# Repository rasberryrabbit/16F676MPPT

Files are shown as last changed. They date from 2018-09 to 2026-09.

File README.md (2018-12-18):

# PIC16F676MPPT
Solar MPPT circuit by 16F676. It did tested and work good.

This is simple MPPT for solar panel. PWM driven by software.

11 mili-ohm N-ch logic level FET(BUK9511) used for current sensor. 
It can replace by 11 mili-ohm or higher Rds-on resistance logic level FET.

BUK9511-55A -> BUK9508-55A
Transistor 2N2222A -> BC547 or compatible
Transistor 2N2907A -> BC557 or compatible

L1 100~330uH

LM358N can replace by other pin-compatible regular OP-AMP. HA17358 is good. It has zero offset voltage.

D8-D9 used for 3.6v Reference. Each has about 1.8v voltage drop.

Q1 gate voltage is 3.6v. It's depend on FET specification.

Q1, Q2 can skip heat spreader with low POWER Solar panel. No heat with 10W panel.

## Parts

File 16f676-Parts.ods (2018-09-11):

Part | Value | Description
R5 | 300k | Solar Voltage Detection | Max 25V
R12 | 47k | Solar Voltage Detection
D5 | 1N4007
D6 | 1N5822A | 3A
D7 | 1N5822A | 6A
C7 | 47u
U1 | 7805
C3 | 100u
C4 | 0.1u
SW1 | PUSH | OP-AMP offset calibration
U3 | PIC16F676
R16 | 10k
R6 | 1k
D4 | LED
R8 | 100k
C6 | 10u
D3 | 1N4001
R7 | 1k
R14 | 4.7k | 3.6v supply
D8 | LED | 3.6v supply
D9 | LED | 3.6v supply
Q3 | 2N2222A | PWM
R9 | 10k
R10 | 1k
C5 | 10u
R11 | 100k
R2 | 100k | OP-AMP | x10 | Max 6A
R3 | 10k | OP-AMP | x10 | Max 6A
R13 | 10k | OP-AMP | x10 | Max 6A
R4 | 100k | OP-AMP | x10 | Max 6A
Q4 | 2N2222A | BOOTSTRAP
Q5 | 2N2907A | BOOTSTRAP
C2 | 1u | BOOTSTRAP
Q2 | BUK9511-55A127 | PWM
D1 | 1N5822A | FET Protect 3A
D10 | 1N5822A | FET Protect 6A
D2 | 1N5822A | 3A
D11 | 1N5822A | 6A
L1 | 330u | 3A
L2 | 330u | 6A
C1 | 100u
Q1 | BUK9511-55A127 | Current Detection | < 11milli Ohm
U2 | HA17358(LM358)
R1 | 2.2k | OP-AMP | ~x5 | Max 6A
R15 | 10k | OP-AMP | ~x5 | Max 6A

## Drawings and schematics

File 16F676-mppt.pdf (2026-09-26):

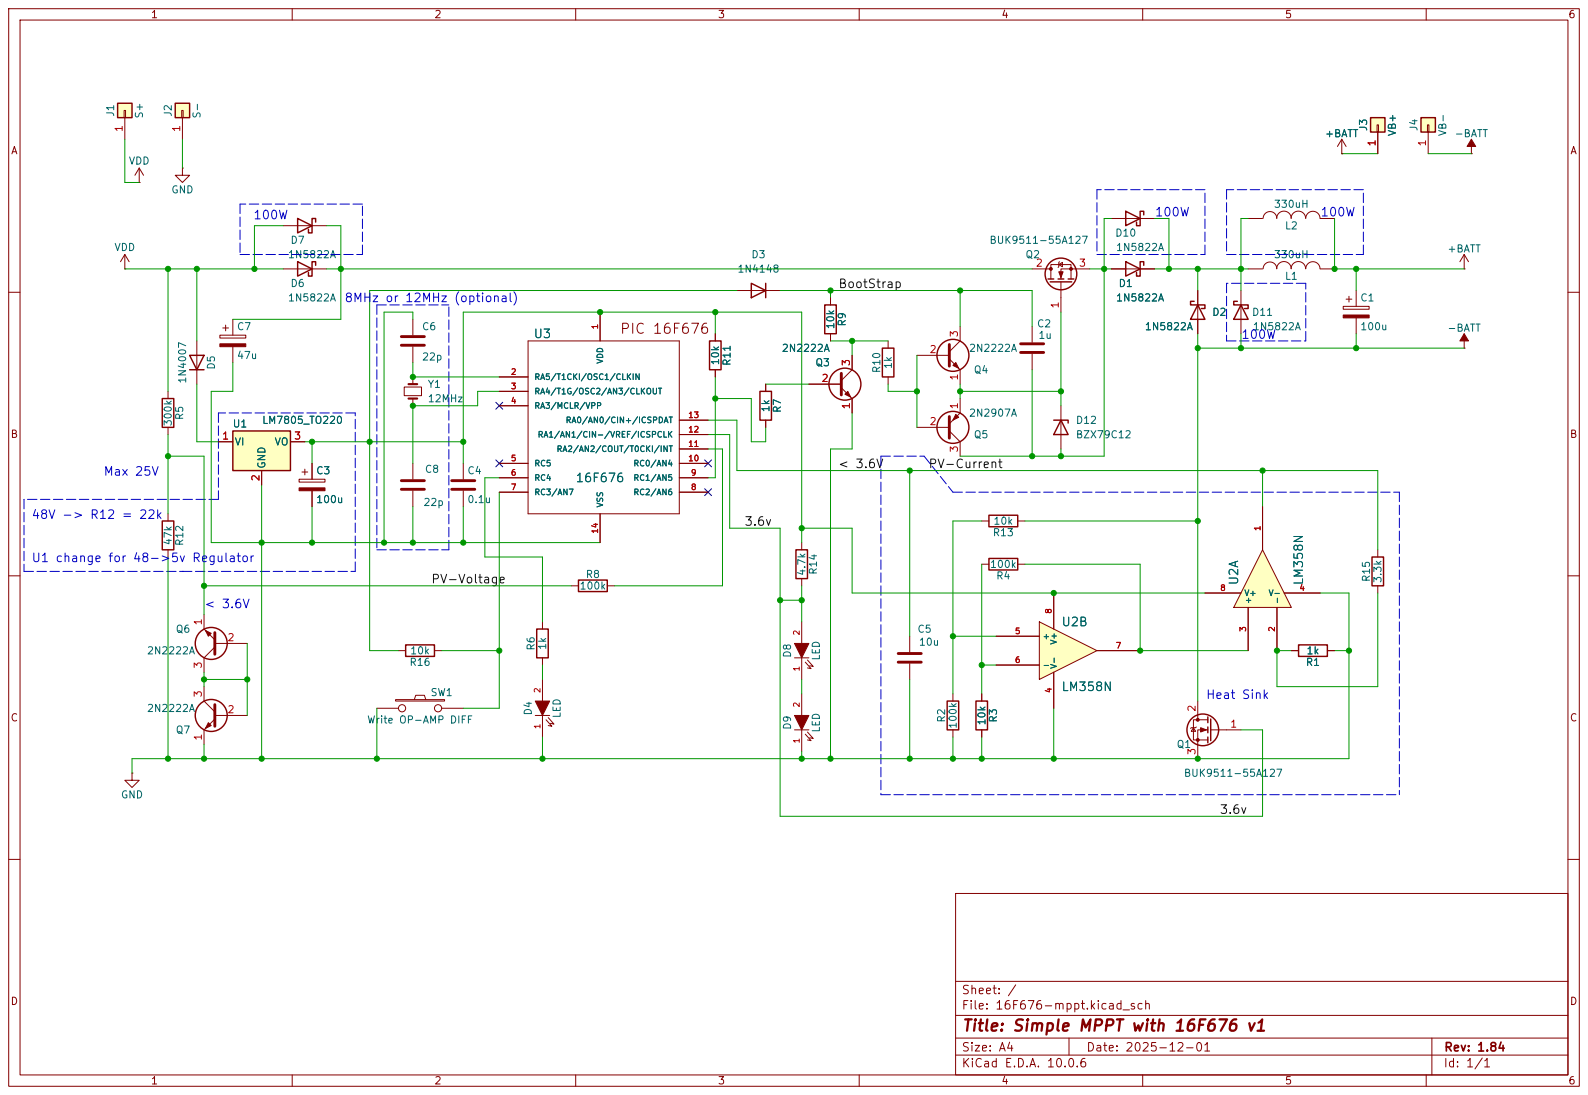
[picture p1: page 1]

100u SW1 Write OP-AMP DIFF R16

1 RA5/T1CKI/OSC1/CLKIN 2 RA4/T1G/OSC2/AN3/CLKOUT 3 RA3/MCLR/VPP 4 RC5 5 RC4 6 RC3/AN7 7 RC2/AN6 8 RC1/AN5 9 RC0/AN4 10 RA2/AN2/COUT/T0CKI/INT 11 RA1/AN1/CIN-/VREF/ICSPCLK 12 RA0/AN0/CIN+/ICSPDAT 13 VSS 14

1 RA5/T1CKI/OSC1/CLKIN 2 RA4/T1G/OSC2/AN3/CLKOUT 3 RA3/MCLR/VPP 4 RC5 5 RC4 6 RC3/AN7 7 RC2/AN6 8 RC1/AN5 9 RC0/AN4 10 RA2/AN2/COUT/T0CKI/INT 11 RA1/AN1/CIN-/VREF/ICSPCLK 12 RA0/AN0/CIN+/ICSPDAT 13 VSS 14 10k R11

File: 16F676-mppt.kicad_sch
Title: Simple MPPT with 16F676 v1

Size: A4 | Rev: 1.84
KiCad E.D.A. 10.0.6 | Id: 1/1

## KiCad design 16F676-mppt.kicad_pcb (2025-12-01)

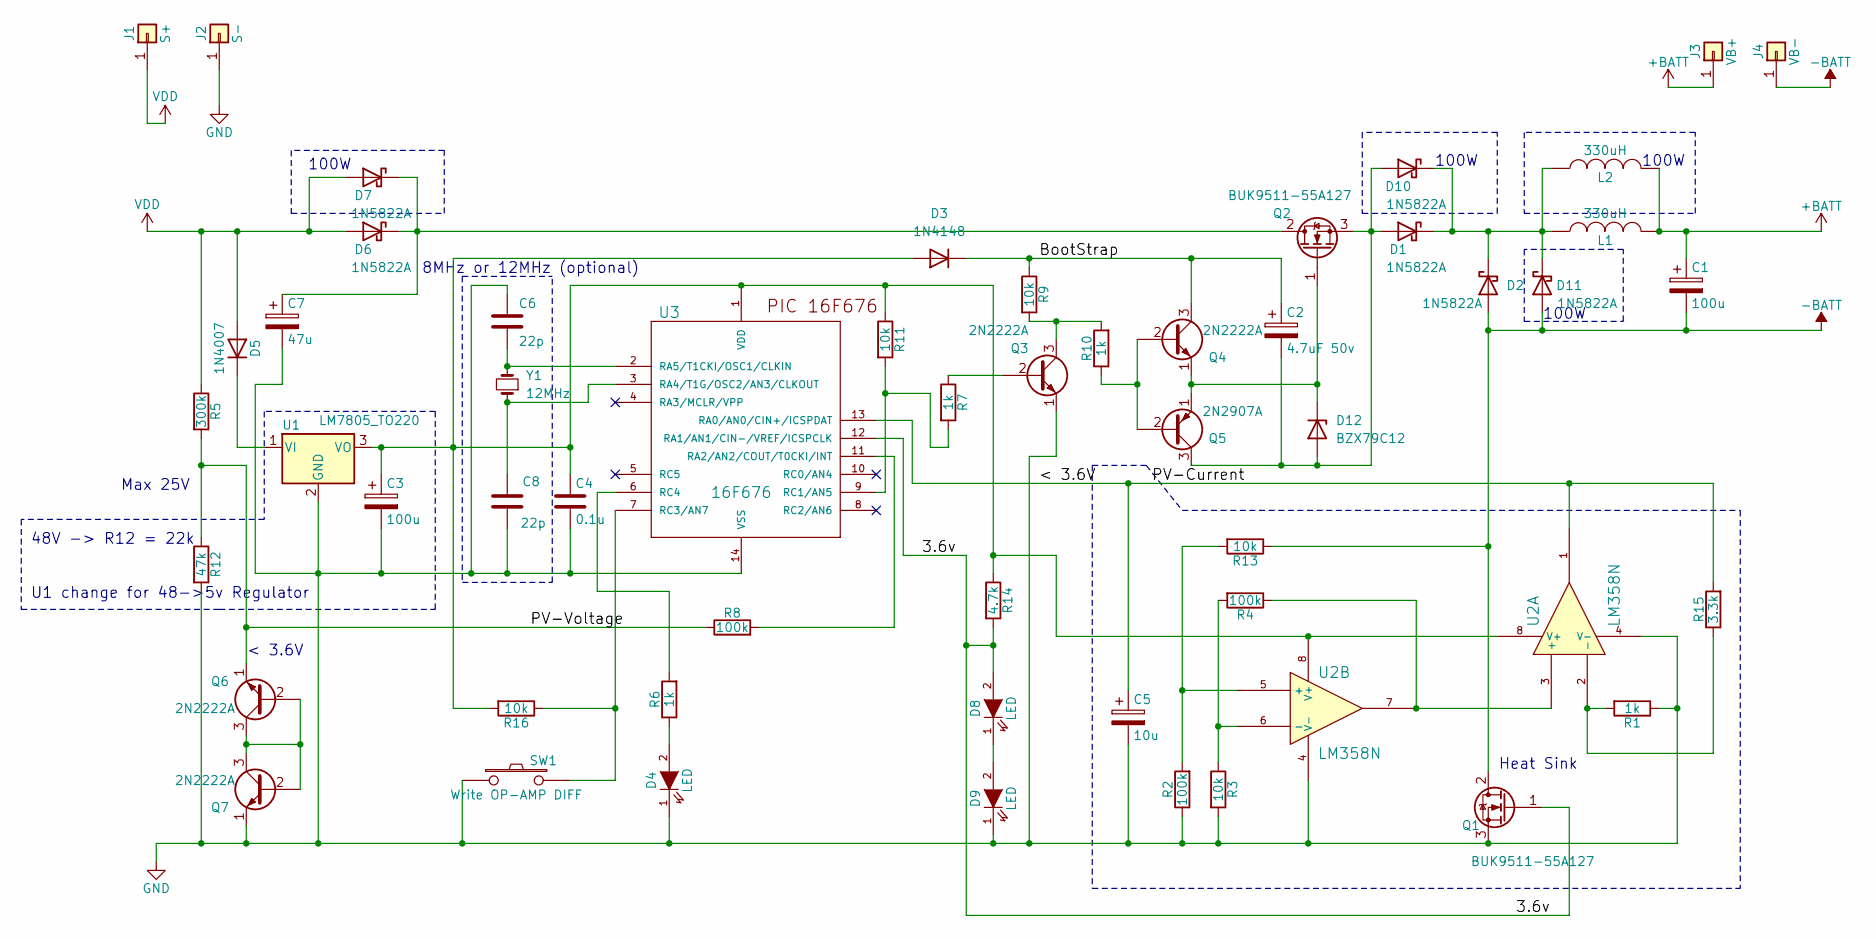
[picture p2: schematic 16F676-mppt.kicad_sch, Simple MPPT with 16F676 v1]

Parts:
C1: 100u; CP_Radial_D12.5mm_P5.00mm
C2: 4.7uF 50v; CP_Radial_D8.0mm_P2.50mm
C3: 100u; CP_Radial_D8.0mm_P2.50mm
C4: 0.1u; C_Disc_D12.5mm_W5.0mm_P7.50mm
C5: 10u; CP_Radial_D8.0mm_P2.50mm
C6, C8: 22p; C_Rect_L4.6mm_W2.0mm_P2.50mm_MKS02_FKP02
C7: 47u; CP_Radial_D12.5mm_P5.00mm
D1, D2, D6, D7, D10, D11: 1N5822A; D_DO-201AD_P15.24mm_Horizontal
D3: 1N4148; D_DO-35_SOD27_P7.62mm_Horizontal
D4, D8, D9: LED; LED_D4.0mm
D5: 1N4007; D_DO-41_SOD81_P10.16mm_Horizontal
D12: BZX79C12; D_DO-35_SOD27_P2.54mm_Vertical_AnodeUp
J1: S+; 1pin
J2: S-; 1pin
J3: VB+; 1pin
J4: VB-; 1pin
L1, L2: 330uH; L_Toroid_Vertical_L33.0mm_W17.8mm_P12.70mm_Pulse_KM-5
Q1, Q2: BUK9511-55A127; TO-220-3_Vertical
Q3, Q4, Q6, Q7: 2N2222A; TO-92_Inline_Wide
Q5: 2N2907A; TO-92_Inline_Wide
R1, R6, R7, R10: 1k; R_Axial_DIN0309_L9.0mm_D3.2mm_P12.70mm_Horizontal
R2, R4, R8: 100k; R_Axial_DIN0309_L9.0mm_D3.2mm_P12.70mm_Horizontal
R3, R9, R11, R13, R16: 10k; R_Axial_DIN0309_L9.0mm_D3.2mm_P12.70mm_Horizontal
R5: 300k; R_Axial_DIN0309_L9.0mm_D3.2mm_P12.70mm_Horizontal
R12: 47k; R_Axial_DIN0309_L9.0mm_D3.2mm_P12.70mm_Horizontal
R14: 4.7k; R_Axial_DIN0309_L9.0mm_D3.2mm_P12.70mm_Horizontal
R15: 3.3k; R_Axial_DIN0309_L9.0mm_D3.2mm_P12.70mm_Horizontal
SW1: Write OP-AMP DIFF; SW_PUSH_6mm
U1: LM7805_TO220; TO-220_Vertical
U2: LM358N; DIP-8_W7.62mm
U3: 16F676; DIP-14_W7.62mm
Y1: 12MHz; Crystal_HC49-U_Vertical

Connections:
+BATT: C1.1, J3.1, L1.2, L2.2
-BATT: C1.2, D2.2 (A), D11.2 (A), J4.1, Q1.2 (D), R13.1
/3.6v: D8.2 (A), Q1.1 (G), R14.2, U3.12 (RA1/AN1/CIN-/VREF/ICSPCLK)
/< 3.6V: C5.1, R15.2, U2.1, U3.13 (RA0/AN0/CIN+/ICSPDAT)
/BootStrap: C2.1, D3.1 (K), Q4.3 (C), R9.1
/PV-Voltage: Q6.1 (E), R5.2, R8.1, R12.1
GND: C3.2, C4.2, C5.2, C6.1, C7.2, C8.2, D4.1 (K), D9.1 (K), J2.1, Q1.3 (S), Q3.1 (E), Q7.1 (E), R1.1, R2.1, R3.2, R12.2, SW1.1, U1.2 (GND), U2.4 (V-), U3.14 (VSS)
unnamed: C2.2, D1.2 (A), D10.2 (A), D12.2 (A), Q2.3 (S), Q5.3 (C)
unnamed: D1.1 (K), D2.1 (K), D10.1 (K), D11.1 (K), L1.1, L2.1
unnamed: C3.1, C4.1, D3.2 (A), R11.1, R14.1, R16.2, U1.3 (VO), U2.8 (V+), U3.1 (VDD)
unnamed: D4.2 (A), R6.1
unnamed: D5.1 (K), U1.1 (VI)
unnamed: C7.1, D6.1 (K), D7.1 (K), Q2.2 (D)
unnamed: D8.1 (K), D9.2 (A)
unnamed: D12.1 (K), Q2.1 (G), Q4.1 (E), Q5.1 (E)
unnamed: Q3.2 (B), R7.1
unnamed: Q3.3 (C), R9.2, R10.2
unnamed: Q4.2 (B), Q5.2 (B), R10.1
unnamed: Q6.2 (B), Q6.3 (C), Q7.2 (B), Q7.3 (C)
unnamed: R4.1, U2.3 (+), U2.7
unnamed: R1.2, R15.1, U2.2 (-)
unnamed: R2.2, R13.2, U2.5 (+)
unnamed: R3.1, R4.2, U2.6 (-)
unnamed: R8.2, U3.11 (RA2/AN2/COUT/T0CKI/INT)
unnamed: C8.1, U3.3 (RA4/T1G/OSC2/AN3/CLKOUT), Y1.1
unnamed: C6.2, U3.2 (RA5/T1CKI/OSC1/CLKIN), Y1.2
unnamed: R7.2, R11.2, U3.9 (RC1/AN5)
unnamed: R16.1, SW1.2, U3.7 (RC3/AN7)
unnamed: R6.2, U3.6 (RC4)
VDD: D5.2 (A), D6.2 (A), D7.2 (A), J1.1, R5.1

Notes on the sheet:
8MHz or 12MHz (optional)
U1 change for 48->5v Regulator
100W
Heat Sink
Max 25V
48V -> R12 = 22k
< 3.6V

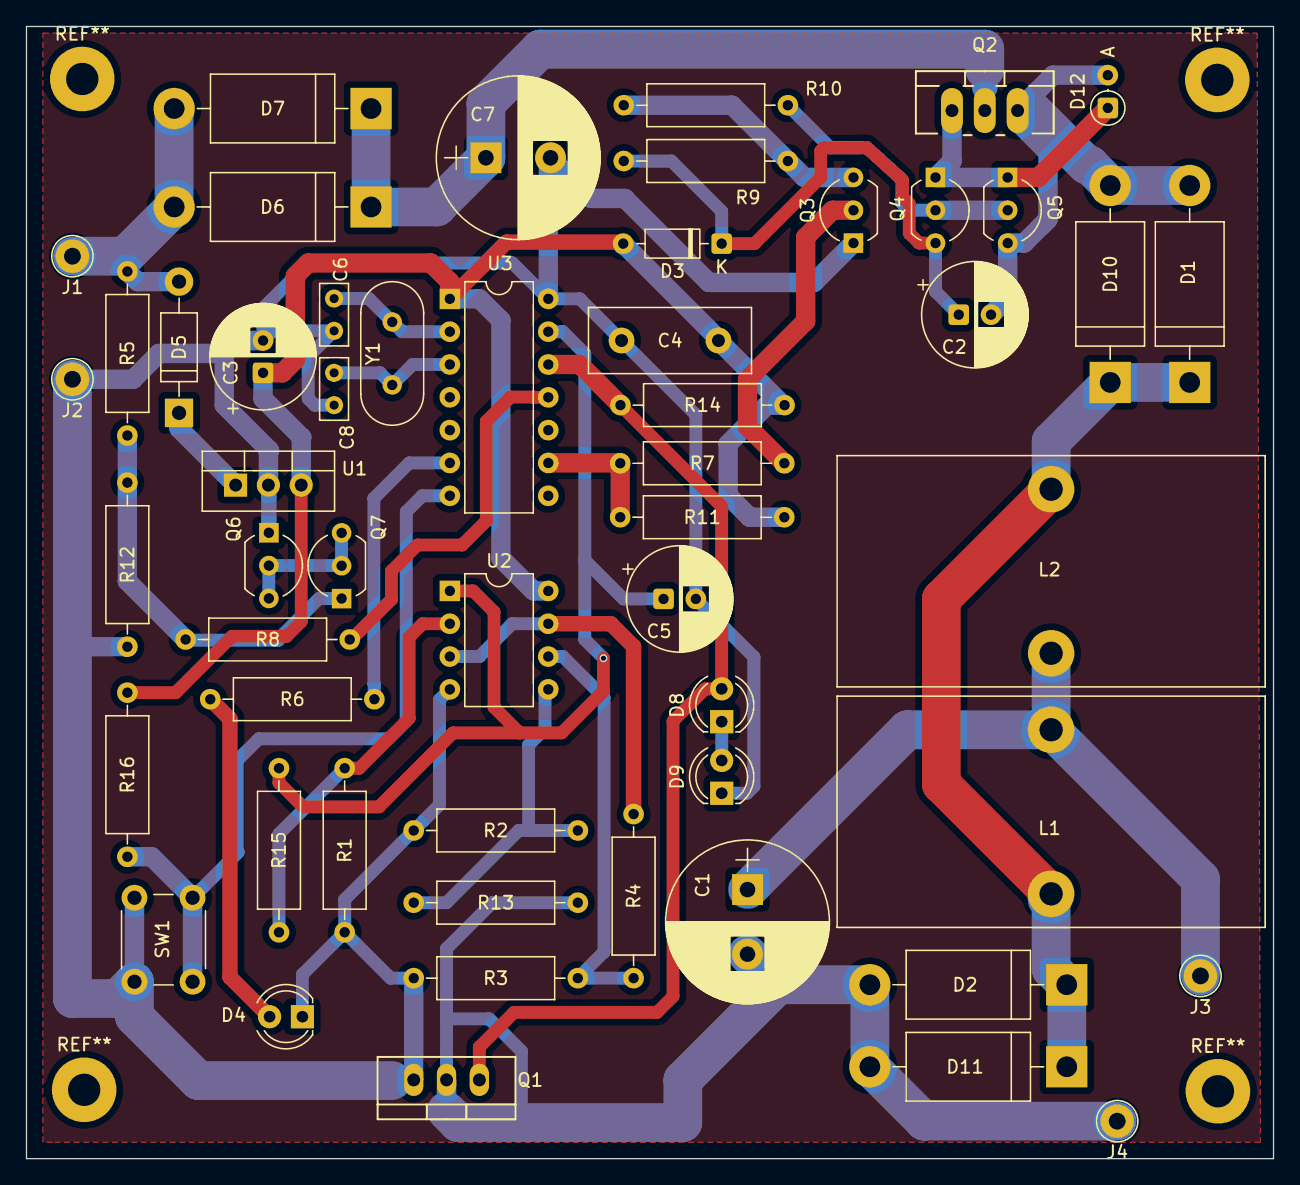
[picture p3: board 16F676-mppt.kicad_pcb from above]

Board: 2 copper layers, 96.5 x 87.6 mm, 54 parts (0 on the bottom side), 30 nets.

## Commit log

2018-06-15 fix missing circuit lines.
    [16F676-mppt.sch]
2018-06-15 add pcb-layout.
2018-06-30 update pcb.
    [16F676-mppt.sch]
2018-07-04 change op-amp multiplier resisters.
    [16F676-mppt.sch]
2018-07-04 update op-amp resister.
    [16F676-mppt.sch]
2018-07-15 more delay on op-amp calibration.
2018-09-04 minor changes.
    [16F676-mppt.sch]
2018-09-09 Change low PWM limit.
2018-09-10 Decrease low PWM limit for low load stability.
2018-09-11 add parts list.
    [16f676-Parts.ods]
2018-11-01 Fix FET Bootstrap capacitor.
    [16F676-mppt.sch]
2018-11-03 More better sustaining PWM.
2018-11-03 Fix low voltage condition. Change method for Max power control.
2018-11-04 fix stall at low voltage.
2018-11-14 Fix timer function.
2018-11-14 Decrease PWM_MAX to prevent FET switch Bootstrap voltage loss.
2018-11-14 make lower again on PWM_MAX.
2018-11-14 fix PWM_MID.
2018-11-14 Due to software PWM, it cannot sustain high voltage on low light.
2018-11-15 Bootstrap capacitor to 47uF.
    [16F676-mppt.sch]
2018-11-17 Revert Bootstrap capacitor to 10uF.
    [16F676-mppt.sch]
2018-11-17 Add resistor
    [16F676-mppt.sch]
2018-11-17 change timer prescaler.
    [16f676MPPT.cfg]
2018-11-17 Add PCB layout.
    [16F676-mppt-B.Cu.gbr, 16F676-mppt-B.Mask.gbr, 16F676-mppt-B.SilkS.gbr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]
2018-11-17 Enable brown out detect.
    [16f676MPPT.cfg]
2018-11-17 change bootstrap diode
    [16F676-mppt.sch]
2018-11-27 R11 to 4.7k
    [16F676-mppt.sch]
2018-11-27 test new firmware.
    [16f676MPPT.cfg]
2018-11-29 Remove R11, it is a lot lower current sesing voltage.
    [16F676-mppt.sch]
2018-11-29 Update PCB Layout.
    [16F676-mppt-B.Cu.gbr, 16F676-mppt-B.Mask.gbr, 16F676-mppt-B.SilkS.gbr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]
2018-11-29 New ADC read method.
2018-11-30 Remove R17.
    [16F676-mppt.sch]
2018-12-12 increase update interval. change ADC read order.
2018-12-13 fix current ADC reading. update optimized update interval.
2018-12-14 C6 to optinal.
    [16F676-mppt.sch]
2018-12-15 Remove C6 for better power calculation. I assume low-pass filter but it make negative effect 'low voltage high current stuck'.
    [16F676-mppt.sch]
2018-12-17 Remove C6.
    [16F676-mppt.sch]
2018-12-18 Add alternative FET.
2018-12-20 R15 -> 4.7k. Current sensing is more higher than expected. 62mA -> 67mV.
    [16F676-mppt.sch]
2018-12-22 update R15 value.
    [16F676-mppt.sch]
2018-12-23 add note for R15.
    [16F676-mppt.sch]
2018-12-26 add clamp.
    [16F676-mppt.sch]
2019-02-13 Fix High-z turn on FET problem.
    [16F676-mppt.sch]
2019-02-15 Change low PWM for boot strap charging.
2019-02-15 Fix R9, R10 Label position.
    [16F676-mppt-B.Cu.gbr, 16F676-mppt-B.Mask.gbr, 16F676-mppt-B.SilkS.gbr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]
2019-02-15 Fix R1, R15 values.
    [16F676-mppt.sch]
2019-02-16 Fix current sensing. I misplace resistors on prototype board.
2019-02-24 Update current sensing resistors.
    [16F676-mppt.sch]
2019-03-25 Add hint for 48V input.
    [16F676-mppt.sch]
2019-05-05 Disable sync with PWM clock.
2019-05-06 Enable PWM checking.
2019-06-09 Remove low voltage protection code.
2021-06-30 Set low PWM to 12.
2021-07-11 C2 -> 4.7uF
    [16F676-mppt.sch]
2021-07-30 Fix Bootstrap problem.
    [16F676-mppt.kicad_pcb, 16F676-mppt.sch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]
2021-07-30 Revert and change diode.
    [16F676-mppt.kicad_pcb, 16F676-mppt.sch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]
2021-08-01 Fix power comparison.
2025-12-01 Fix circuit.
    [16F676-mppt.kicad_sch]
2025-12-01 Fix PWM firmware.
2025-12-01 Add optional external xtal.
    [16F676-mppt.kicad_sch]
2025-12-01 Update SCH and PCB files.
    [16F676-mppt.kicad_pcb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]
2026-07-23 Try to fix low power whean decreasing PV power.
2026-07-31 Remove voltage multiplication operation.
2026-07-31 Change the current measurement method
2026-08-12 Restore voltage multiplier.
2026-08-13 Loosen power low checking.
2026-08-13 Use ADC average values.
2026-09-22 Using dead band at Power monitoring.
2026-09-23 Disable low current checking.
2026-09-24 Try to fix stalling.
2026-09-25 To more reliably compare cumulative power changes, we adjust the update time and limit the maximum deadband at high powers to less than 1%.
2026-09-25 Update PWM @ no load.
2026-09-26 Change capacitors.
    [16F676-mppt.kicad_sch]
2026-09-26 Update capacitor footprint.
    [16F676-mppt.kicad_sch]
